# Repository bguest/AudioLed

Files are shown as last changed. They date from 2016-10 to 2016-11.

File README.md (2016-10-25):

# AudioLed
Board to drive a string of WS2801 chips using audio and a MSGEQ7

# Setup

## Attaching FTDI
The FTDI Cable plugs in under the 12v Power Connector. The FTDI Grounds are close to the center of
the board, the DTR is closer to the edge of the board.

If the power connector is in the upper right of the board facing up the FTDI pins will be

GND, GND, VCC, RXI, RXO, DTR

## Setting up Arduino and Compiling the Code (MAC)

1. Clone this repo to `~/Documents/Arduino` with `cd ~/Documents/Arduino && git clone git@github.com:bguest/AudioLed.git`
2. Change directory to AudioLED with `cd AudioLed`
3. Mod setup script `chmod +x setup.sh`
4. Run Setup `.\setup.sh` this will clone correct versions of `Adafruit_WS2801` and `Arduino-IRremote`
5. Download Arduino v1.6.6 (May not compile with later versions of Arduino)
6. Launch Arduino v1.6.6
7. Open AudioLED
8. Set board to `Arduino Pro or Pro Mini`
9. Set processor to `ATmega328 (5V, 16MHz)`
10. Verify and Upload Code

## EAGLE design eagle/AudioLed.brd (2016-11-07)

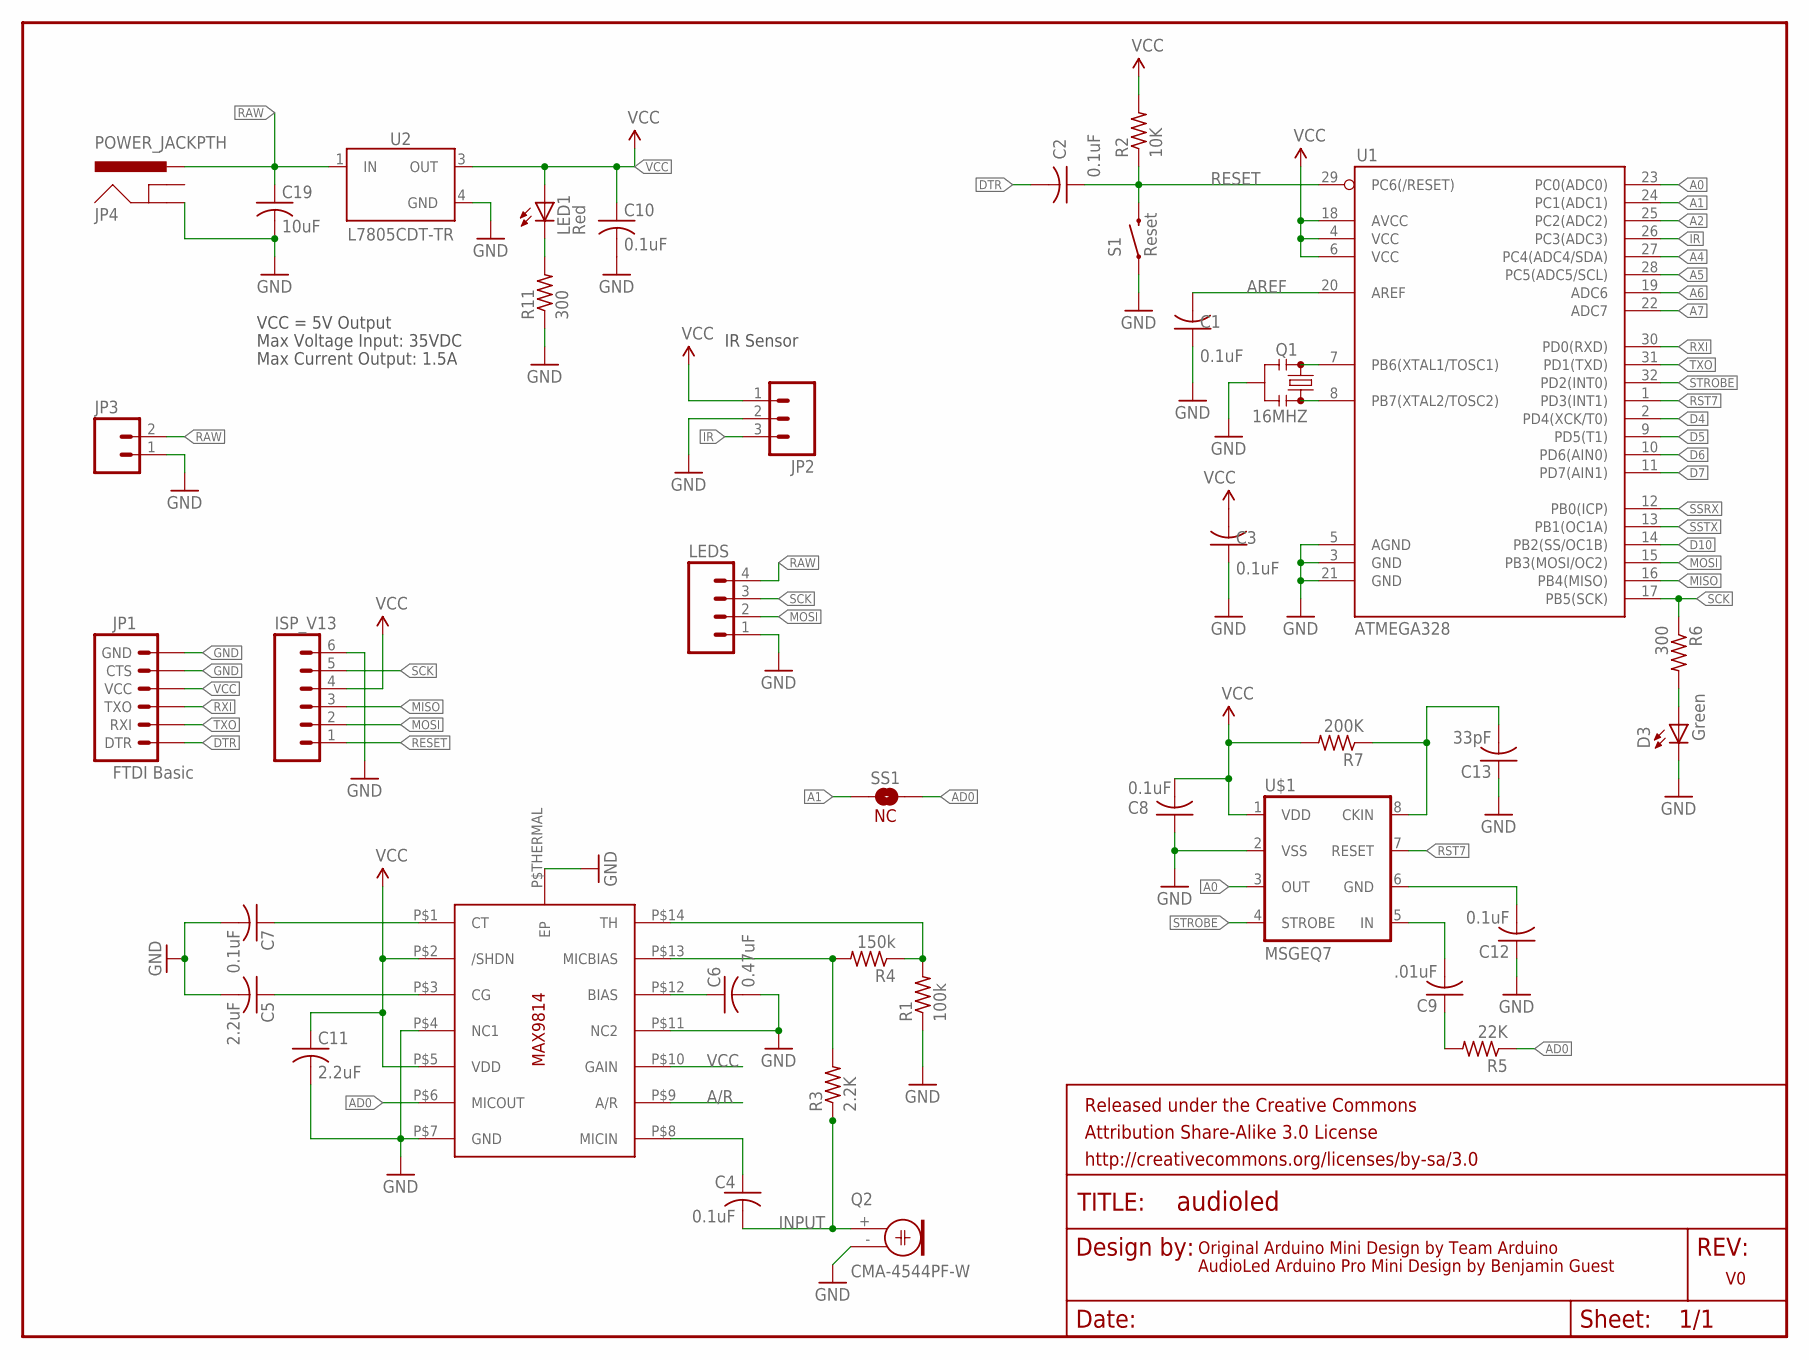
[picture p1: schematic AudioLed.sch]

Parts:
C1, C2, C3, C8, C10, C12: 0.1uF; C0805
C4, C7: 0.1uF; C0805K
C5, C11: 2.2uF; C0805K
C6: 0.47uF; C0805K
C9: .01uF; C0805
C13: 33pF; C0805
C19: 10uF; C0805
D3: Green; CHIPLED_0805
FRAME1: FRAME-LETTER; CREATIVE_COMMONS
ISP_V13: M06SIP; 1X06
JP1: FTDI Basic; 1X06
JP2: M03JST-PTH; JST-3-PTH
JP3: M02JST-PTH-2; JST-2-PTH
JP4: POWER_JACKPTH; POWER_JACK_PTH
LED1: Red; CHIPLED_0805
LEDS: M04JST-PTH; JST-4-PTH
Q1: 16MHZ; RESONATOR-SMD
Q2: CMA-4544PF-W; 9.7ELECTRET
R1: 100k; R0805
R2: 10K; M0805
R3: 2.2K; R0805
R4: 150k; R0805
R5: 22K; M0805
R6, R11: 300; M0805
R7: 200K; M0805
S1: Reset; TACTILE-SWITCH-SMD-ALT01
SS1: NC; SJ_2S
U1: ATMEGA328; TQFP32-08
U2: L7805CDT-TR; DPAK
U4: MAX9814TDFN14; TDFN14_3X3MM
U$1: MSGEQ7; DIL08-ROUND

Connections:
A0: U1.23 (PC0(ADC0)), U$1.3 (OUT)
A1: SS1.1, U1.24 (PC1(ADC1))
A2: U1.25 (PC2(ADC2))
A4: U1.27 (PC4(ADC4/SDA))
A5: U1.28 (PC5(ADC5/SCL))
A6: U1.19 (ADC6)
A7: U1.22 (ADC7)
A/R: U4.P$9 (A/R)
AD0: R5.1, SS1.2, U4.P$6 (MICOUT)
AREF: C1.2, U1.20 (AREF)
D4: U1.2 (PD4(XCK/T0))
D5: U1.9 (PD5(T1))
D6: U1.10 (PD6(AIN0))
D7: U1.11 (PD7(AIN1))
D10: U1.14 (PB2(SS/OC1B))
DTR: C2.2, JP1.1 (DTR)
GND: C1.1, C3.1, C5.2, C6.2, C7.2, C8.1, C10.2, C11.2, C12.1, C13.1, C19.2, D3.C, ISP_V13.6, JP1.5 (CTS), JP1.6 (GND), JP2.2, JP3.1, JP4.GND, LEDS.1, Q1.2, Q2.- (1), R1.1, R11.1, S1.1, S1.2 (1), U1.3 (GND), U1.5 (AGND), U1.21 (GND), U2.4 (GND), U4.P$4 (NC1), U4.P$7 (GND), U4.P$11 (NC2), U4.P$THERMAL (EP), U$1.2 (VSS)
INPUT: C4.2, Q2.+ (2), R3.1
IR: JP2.3, U1.26 (PC3(ADC3))
MISO: ISP_V13.3, U1.16 (PB4(MISO))
MOSI: ISP_V13.2, LEDS.2, U1.15 (PB3(MOSI/OC2))
unnamed: Q1.3, U1.8 (PB7(XTAL2/TOSC2))
unnamed: Q1.1, U1.7 (PB6(XTAL1/TOSC1))
unnamed: C6.1, U4.P$12 (BIAS)
unnamed: LED1.C, R11.2
unnamed: C4.1, U4.P$8 (MICIN)
unnamed: C9.1, R5.2
unnamed: D3.A, R6.2
unnamed: C7.1, U4.P$1 (CT)
unnamed: C5.1, U4.P$3 (CG)
unnamed: R1.2, R4.1, U4.P$14 (TH)
unnamed: R3.2, R4.2, U4.P$13 (MICBIAS)
unnamed: C9.2, U$1.5 (IN)
unnamed: C12.2, U$1.6 (GND)
unnamed: C13.2, R7.1, U$1.8 (CKIN)
RAW: C19.1, JP3.2, JP4.PWR, LEDS.4, U2.1 (IN)
RESET: C2.1, ISP_V13.1, R2.1, S1.3 (2), S1.4 (2), U1.29 (PC6(/RESET))
RST7: U1.1 (PD3(INT1)), U$1.7 (RESET)
RXI: JP1.3 (TXO), U1.30 (PD0(RXD))
SCK: ISP_V13.5, LEDS.3, R6.1, U1.17 (PB5(SCK))
SSRX: U1.12 (PB0(ICP))
SSTX: U1.13 (PB1(OC1A))
STROBE: U1.32 (PD2(INT0)), U$1.4 (STROBE)
TXO: JP1.2 (RXI), U1.31 (PD1(TXD))
VCC: C3.2, C8.2, C10.1, C11.1, ISP_V13.4, JP1.4 (VCC), JP2.1, LED1.A, R2.2, R7.2, U1.4 (VCC), U1.6 (VCC), U1.18 (AVCC), U2.3 (OUT), U4.P$2 (/SHDN), U4.P$5 (VDD), U4.P$10 (GAIN), U$1.1 (VDD)

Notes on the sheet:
Original Arduino Mini Design by Team Arduino
AudioLed Arduino Pro Mini Design by Benjamin Guest
Max Voltage Input: 35VDC
Max Current Output: 1.5A
VCC = 5V Output
IR Sensor

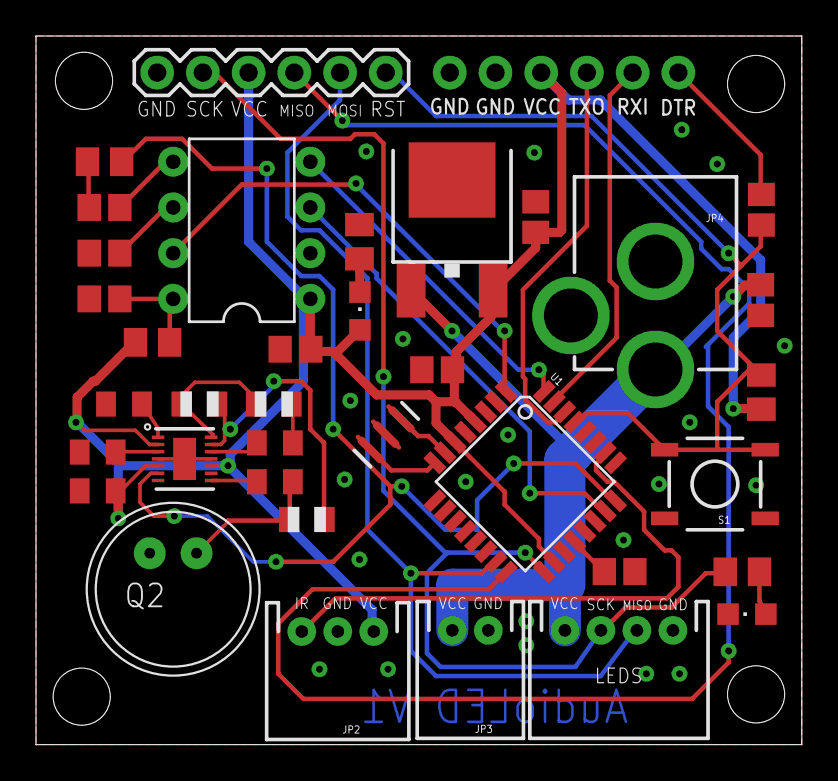
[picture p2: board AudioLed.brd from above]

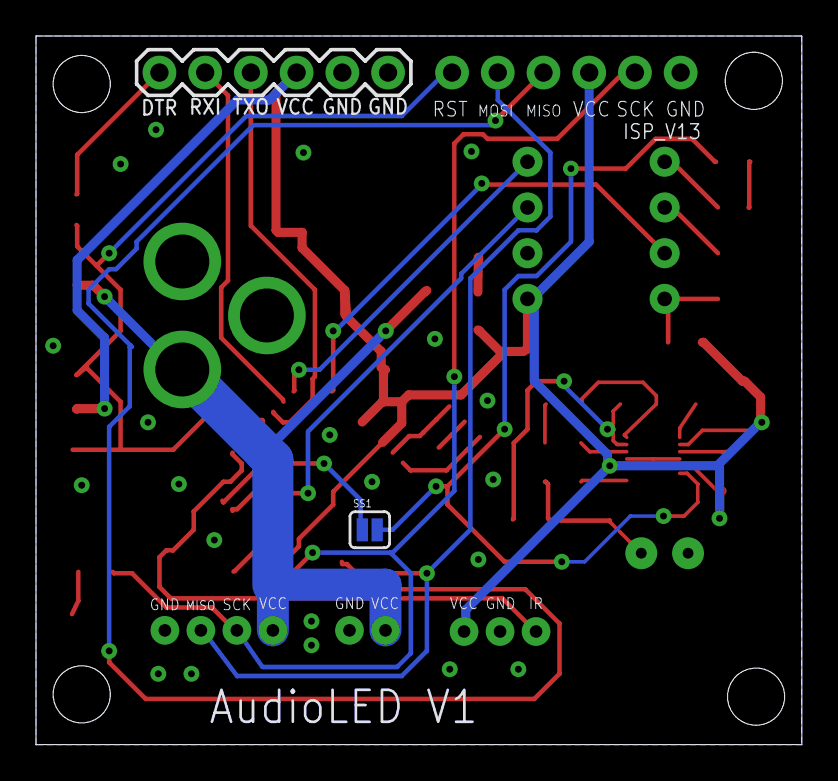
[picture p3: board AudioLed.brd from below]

Board: 2 copper layers, 42.5 x 39.4 mm, 39 parts (2 on the bottom side), 32 nets.

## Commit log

2016-01-05 Fix Incorrectly Labled Capacitor
    [AudioLed.brd, AudioLed.sch]
2016-01-06 Add Dimensions
    [AudioLed.brd]
2016-01-25 Move trace slightly
    [AudioLed.brd, AudioLed.sch]
2016-01-25 Replace bad resonator with SparkFun Resonator
    [AudioLed.brd, AudioLed.sch]
2016-02-19 Add Hue array, fix tempo button
2016-02-23 Switch to hsv calculations add drizly color switch
2016-02-25 Switch to RollOff
2016-03-01 Add Visual For Current Push Layer
2016-04-16 Bump Board Version to V1
    [AudioLed.brd]
2016-10-27 Small Tweeks
    [AudioLed.brd, AudioLed.sch]

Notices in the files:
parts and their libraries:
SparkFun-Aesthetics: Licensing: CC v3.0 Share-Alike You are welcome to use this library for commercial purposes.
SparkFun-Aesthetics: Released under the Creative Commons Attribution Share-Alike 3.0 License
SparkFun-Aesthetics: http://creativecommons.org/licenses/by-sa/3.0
